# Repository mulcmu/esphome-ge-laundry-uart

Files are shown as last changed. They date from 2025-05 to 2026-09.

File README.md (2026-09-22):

# ESPHome GE Laundry UART

Local Home Assistant control and monitoring for compatible GE appliances through ESPHome and the appliance's GEA serial bus.

> [!WARNING]
> The appliance uses an 8P8C modular connector that looks like Ethernet, but it is **not Ethernet**. Do not connect it to network equipment.

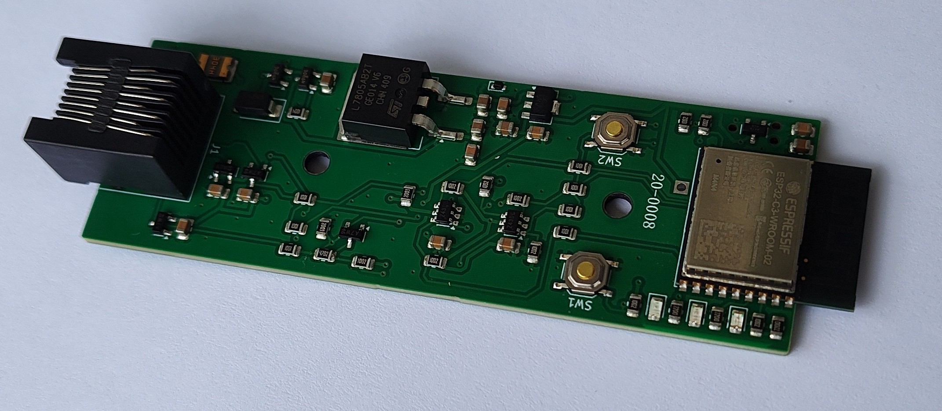
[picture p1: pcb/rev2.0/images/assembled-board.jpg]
Assembled Rev 2-era adapter


The project began as an effort to integrate a GE washer and dryer with Home Assistant. An ESP32 powered by the appliance communication port reports information such as remaining time and cycle completion through ESPHome. Early work involved researching the GEA2 and GEA3 protocols and the U+ Connect module; later, [GE Appliances](https://github.com/geappliances) and [FirstBuild](https://firstbuild.com/inventions/home-assistant-adapter/) published additional hardware and protocol information. The maintained ESPHome implementation now lives in [mguaylam/esphome-gea](https://github.com/mguaylam/esphome-gea), while this repository provides compatible hardware, reference configurations, manufacturing files, and enclosures.

## Getting started

### I already have a board

Follow the [firmware setup guide](firmware/README.md) to choose a GEA2 or GEA3 configuration, flash the board, connect it to Home Assistant, and check the status LEDs. The [Rev 2 enclosure](case/rev2/README.md) includes ready-to-print files.

### I want to order a board

Start with [PCB Rev 2.2](pcb/rev2.2/README.md), then follow the [step-by-step ordering guide](pcb/ORDERING.md). Rev 2.2 corrects the known Rev 2.0 and Rev 2.1 board-file problems.

**Current status:** Rev 2.2 is the recommended manufacturing candidate; physical testing is still pending. A JLCPCB quote checked on September 19, 2026 was **$78.07 before shipping and tax for five fully assembled boards**, or about **$15.61 per board**. Prices and component availability can change.

Older boards and the complete change history are listed in the [PCB revision index](pcb/README.md). Hardware contributors should also read the [contribution guide](CONTRIBUTING.md).

## Related projects

- [GE Appliances organization](https://github.com/geappliances)
- [FirstBuild Home Assistant adapter](https://firstbuild.com/inventions/home-assistant-adapter/)
- [puddly/casserole](https://github.com/puddly/casserole)
- [GEMakers/green-bean](https://github.com/GEMakers/green-bean)
- [doitaljosh/gea-interface-board](https://github.com/doitaljosh/gea-interface-board)
- [doitaljosh/ge-appliances-re](https://github.com/doitaljosh/ge-appliances-re)
- [doitaljosh/geabus-documentation](https://github.com/doitaljosh/geabus-documentation)
- [simbaja/gehome](https://github.com/simbaja/gehome)
- [GE Appliances Home Assistant adapter](https://github.com/geappliances/home-assistant-adapter)
- [GE Appliances Home Assistant examples](https://github.com/geappliances/home-assistant-examples)
- [GE Appliances Home Assistant bridge](https://github.com/geappliances/home-assistant-bridge)

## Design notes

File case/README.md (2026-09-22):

# Enclosures

Enclosure files are grouped by the PCB family they were designed to fit.

[Back to the project overview](../README.md)

| Enclosure | Intended hardware | Status |
| --- | --- | --- |
| [Rev 2 enclosure](rev2/README.md) | Rev 2.x board outline | Existing printable design; Rev 2.2 fit still requires a physical check. |

The editable CAD source, printable files, and documentation images are kept separately. The final check is printing the enclosure and test-fitting an assembled board.

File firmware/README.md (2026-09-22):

# Set up and use a Rev 2.x board

These examples use the maintained [ESPHome GEA component](https://github.com/mguaylam/esphome-gea) to connect the adapter to Home Assistant.

[Back to the project overview](../README.md) · [Recommended PCB Rev 2.2](../pcb/rev2.2/README.md) · [Revision history](../pcb/README.md)

## Choose a configuration

| Configuration | Connection | Typical use |
| --- | --- | --- |
| [`gea2.yaml`](gea2.yaml) | GPIO5 TX and GPIO10 RX, inverted, 19,200 baud | Rev 2.x reference for GEA2 appliances. |
| [`gea3.yaml`](gea3.yaml) | GPIO21 TX and GPIO20 RX, non-inverted, 230,400 baud | Rev 2.x reference for GEA3 appliances. |

The appliance model determines whether it uses GEA2 or GEA3. Start with a configuration already known to work with your appliance rather than trying both while connected.

## Prepare ESPHome

If ESPHome is not installed yet, start with the official [ESPHome installation guide](https://esphome.io/install/) and [getting-started guide](https://esphome.io/install/getting-started/).

1. Copy the matching YAML file into your ESPHome configuration directory.
2. Change the `name` and `upper_name` substitutions near the top of the file.
3. Add these values to the `secrets.yaml` file in the same directory:

```yaml
wifi_ssid: "..."
wifi_password: "..."
esp_home_ota_pw: "..."
```

You can use the ESPHome Device Builder or the command line. The examples are starting points, so appliance-specific entities may need to be added or changed.

## First flash

Rev 2.x boards do not have USB. The first flash needs a **3.3 V logic** USB-to-UART adapter connected to the unpopulated J2 holes or the J3 Tag-Connect pads. Do not connect 5 V to these pins.

| J2 pin | Board signal | Connect to |
| --- | --- | --- |
| 1, square pad | 3.3 V | A regulated 3.3 V source capable of powering the ESP32 |
| 2 | Ground | Adapter ground |
| 3 | Boot | Ground only while entering the bootloader |
| 4 | Board TX | Adapter RX |
| 5 | Board RX | Adapter TX |
| 6 | Enable | Optional reset control |

Use only one power source at a time. Some USB-to-UART adapters cannot provide enough 3.3 V current for an ESP32 Wi-Fi board; use a separate regulated 3.3 V supply when needed and connect its ground to the adapter ground.

1. Connect J2 Boot to Ground.
2. Apply 3.3 V power, or power-cycle the board if it was already on. This starts the serial bootloader.
3. In ESPHome Device Builder, choose **Install** and select the serial adapter. With the command line, run:

   ```console
   esphome run your-config.yaml --device /dev/cu.your-usb-serial-device
   ```

4. When the upload finishes, disconnect Boot from Ground and power-cycle the board.

Later updates can be installed over Wi-Fi from ESPHome Device Builder. From the command line, run the same `esphome run` command and choose the network device when prompted.

## Connect to the appliance

1. Disconnect the programming adapter and install the board in its enclosure.
2. With the appliance off, connect the adapter to its service port. This connector is not Ethernet.
3. Power the appliance and wait for the board to join Wi-Fi.
4. Add the discovered ESPHome device in Home Assistant.

With the supplied configurations, the green LED shows Wi-Fi connection and the yellow LED shows GEA bus activity. The red LED is available to ESPHome but is not assigned a status by these examples.

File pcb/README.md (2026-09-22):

# PCB revisions

This directory keeps every board revision in a separate package so source files, manufacturing files, and review files do not get mixed between revisions.

[Back to the project overview](../README.md) · [PCB ordering guide](ORDERING.md)

> [!IMPORTANT]
> For a new build, start with [Rev 2.2](rev2.2/README.md). Older revisions are retained for repair information and project history.

## What the folders mean

- `design/` contains the editable KiCad project. A `.pretty` directory under `footprints/` is a KiCad footprint library: it defines the exact copper pads, drill holes, silkscreen, and component outline used on the board. A project `fp-lib-table` maps the library name used by the board to that local directory so footprints resolve from a clean clone. A `models/` directory, when present, contains optional 3D component shapes.
- `manufacturing/` contains files sent to a PCB assembler. Gerbers describe copper, holes, solder mask, and silkscreen; the BOM lists components; the CPL lists component positions and rotations.
- `validation/` contains files used to review the design, such as schematic PDFs, board views, drill maps, and ERC/DRC reports.
- `images/` contains photographs and explanatory renders used by documentation. Images are not manufacturing inputs.

## Revision index

| Revision | Status | Available material |
| --- | --- | --- |
| [Rev 2.2](rev2.2/README.md) | Manufacturing candidate | Corrected KiCad source, matched factory package, and validation exports. |
| [Rev 2.1](rev2.1/README.md) | Built; superseded | KiCad 9 source, JLCPCB package, drill maps, and repair image. |
| [Rev 2.0](rev2.0/README.md) | Built; superseded | PCBA archive, schematic, board model, renders, and photographs. |
| [Rev 1.0](rev1.0/README.md) | Historical | Gerber archive only. |

> [!IMPORTANT]
> Rev 2.0 and Rev 2.1 have swapped RX/TX silkscreen labels. Their U1 reset supervisor can also cause ESP32 boot loops. Do not treat either manufacturing package as a corrected design.

Rev 2.2 addresses those known board-file problems but is not proven until assembled boards pass electrical, appliance, and enclosure testing. Use only the three matched files in its `manufacturing/` directory when ordering.

Not every revision has the same files. The table lists what is actually available; missing source files, exports, and images were not recreated.

## Historical revisions

- Rev 0.1 had unconnected grounds discovered after ordering.
- Rev 0.2 corrected the grounds but needed a diode orientation bodge and resistor changes.
- Rev 0.3 added test points, an LED, a push button, and protection diodes; three boards were tested.
- Rev 1.0 added configurable resistors for inverted GEA2 serial signaling.
- Rev 2.0 introduced an assembly-oriented ESP32-C3 design.
- Rev 2.1 updated that design and migrated its source to KiCad 9.

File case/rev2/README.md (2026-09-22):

# Rev 2 enclosure

This enclosure was designed around the Rev 2.x PCB outline. The editable Fusion 360 archive, neutral CAD export, printable STL files, and documentation images are kept separately.

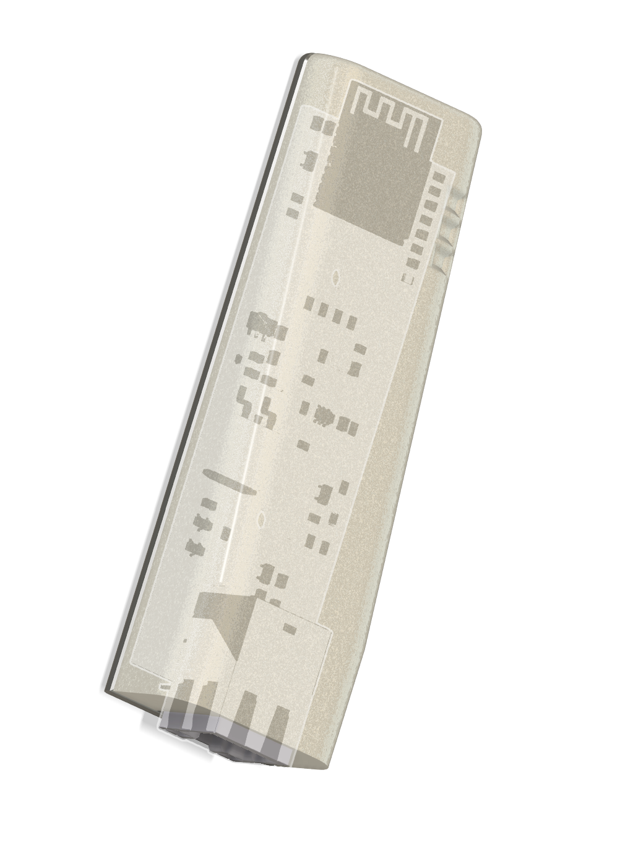
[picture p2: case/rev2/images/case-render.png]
Rev 2 enclosure render


*Exterior enclosure render.*

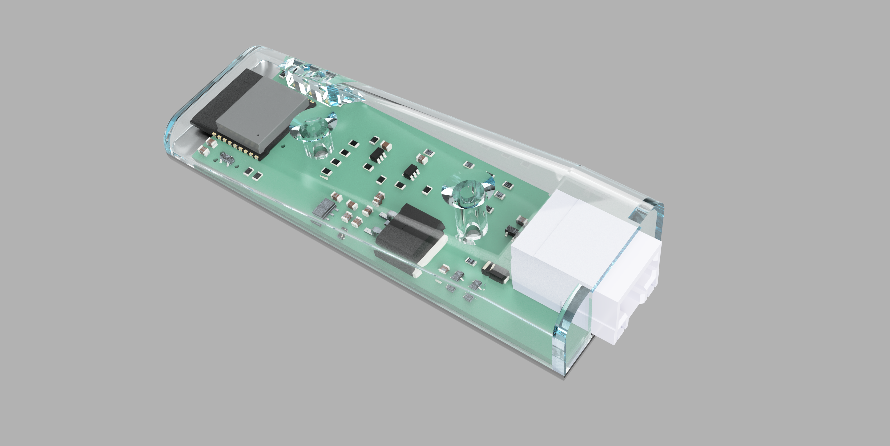
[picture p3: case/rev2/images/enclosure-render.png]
Rev 2 enclosure with board


*Exploded enclosure view showing the board position.*

## Files

- [Editable Fusion 360 archive](v2-case.f3z)
- [STEP export](exports/v2-case.step)
- [Base STL](exports/v2-case-base.stl)
- [Lid STL](exports/v2-case-lid.stl)
- [Case render](images/case-render.png)
- [Enclosed-board render](images/enclosure-render.png)
- [Example support arrangement](images/print-supports.png)

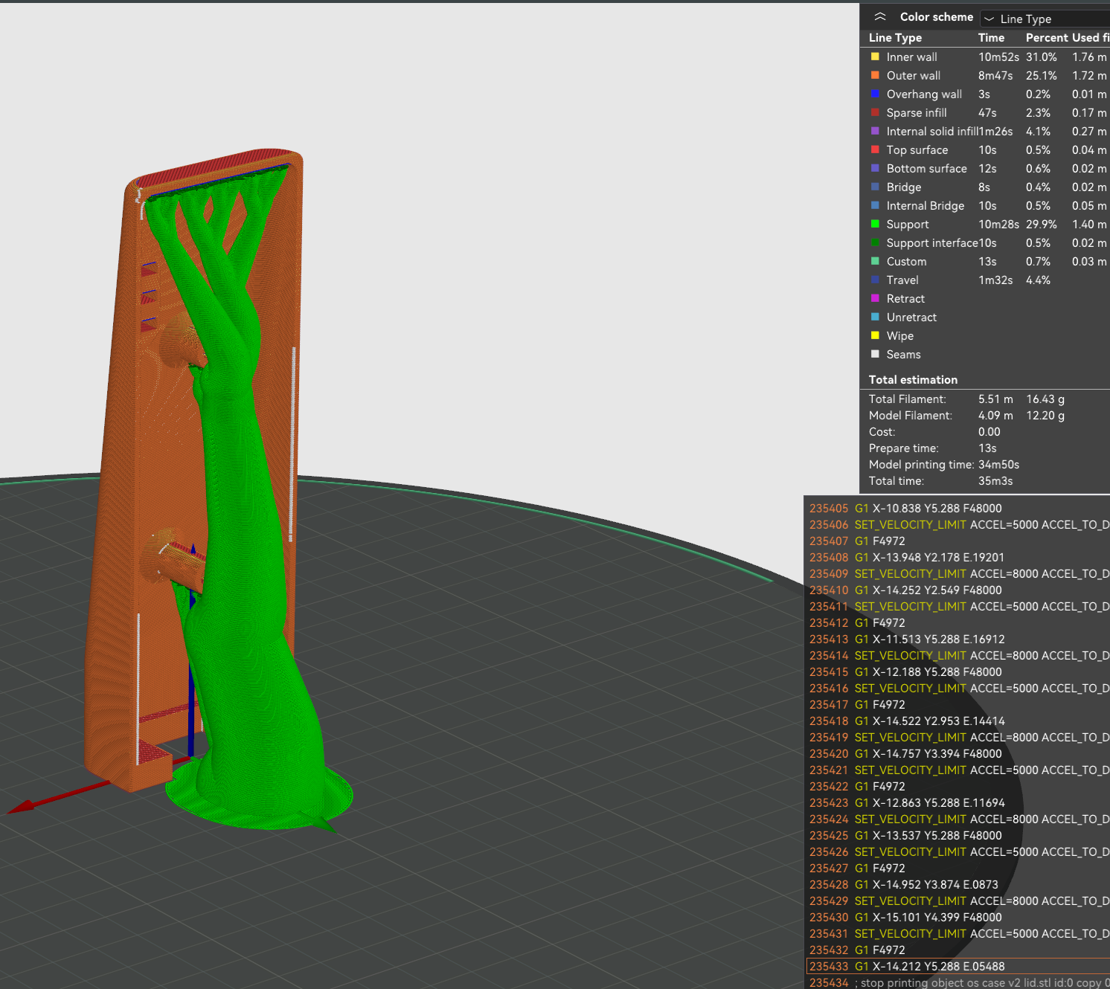
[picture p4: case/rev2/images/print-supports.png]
Example print support arrangement


*Example slicer support arrangement.*

The support image is an example, not a required slicer profile. Confirm orientation, support placement, connector access, button access, antenna clearance, and populated-board fit before relying on a print.

[Back to the enclosure index](../README.md) · [PCB revisions](../../pcb/README.md)

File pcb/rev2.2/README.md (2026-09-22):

# PCB Rev 2.2 manufacturing candidate

This directory contains the matched files needed to quote a small revision 2.2 prototype batch. Revision 2.2 is not a proven hardware release until physical boards pass bring-up testing.

Start with the [KiCad project](design/OnionStraws.kicad_pro). Use the shared [PCB ordering guide](../ORDERING.md) with the three matched Rev 2.2 manufacturing files; do not substitute files from an older revision.

## What changed

- `U1` is an optional voltage-monitor chip intended to reset the ESP32 when its supply is too low. It caused repeated boot loops on existing Rev 2 boards, so Rev 2.2 leaves it uninstalled. Its small footprint remains on the board for rework, but the factory BOM and placement data exclude it. R3 still keeps the ESP32 enabled. Neither board button is wired as a reset button; reset requires a power cycle or an external reset connection.
- The rear silkscreen identifies the board as revision 2.2.
- The appliance-facing connector labels now use the adapter/ESP perspective:
  - pin 5, `Full TX`: adapter/ESP TX to appliance RX;
  - pin 4, `Full RX`: appliance TX to adapter/ESP RX.
- `Q1` is one of two identical power-control transistors. Its supplier catalog field was blank, while `Q2` already identified the correct part. Rev 2.2 gives both the same LCSC catalog number so JLCPCB can source the part automatically. This is purchasing metadata only and does not change the circuit.
- `J1` retains the original low-cost EVERCOM `5301-8P8C` (`C3097717`). Its eight signal holes now use the manufacturer's recommended 0.90 mm diameter; the connector position and two 3.20 mm locating holes are unchanged. Confirm the connector orientation and drill pattern in the vendor preview and prototype batch before production use.
- `JP1` and `JP2` are existing three-pad solder selectors on the bottom of the board. `JP1` selects the FirstBuild-compatible signal mapping. `JP2` selects the normal or alternate appliance power input. Both default to pads 1-2 because that copper bridge is part of the manufactured board; changing one requires cutting that bridge and soldering pads 2-3.

Rev 2.2 does not add a new user-operated jumper, programming connector, or automatic pin-1/pin-3 power-selection circuit. The service pads and solder selectors described below already existed in Rev 2.1 and remain unpopulated. Do not combine the [Rev 2.1 package](../rev2.1/README.md) with Rev 2.2 files.

## Debug and programming access

Rev 2.2 preserves two service interfaces, both excluded from factory assembly:

- `J2` is a row of six 2.54 mm through-holes carrying, from square pin 1 to pin 6, 3.3 V, ground, boot, board transmit, board receive, and enable. Revision 2.2 leaves these holes unpopulated. A header may be soldered into them later, or a custom pogo fixture may contact them.
- `J3` carries the same six signals on a flat, bottom-side Tag-Connect `TC2030-IDC-NL` pattern. It has copper contacts and three alignment holes but no connector component, so it adds no BOM or assembly cost. A compatible cable or reusable pogo clip can make a no-solder connection.

Neither interface is USB. Connecting a Mac requires a 3.3 V USB-to-UART adapter plus the matching cable or fixture; do not connect 5 V logic to these signals. The current Rev 2 enclosure covers both service areas and is unchanged in this revision.

## Manufacturing files

- [`GERBER-OnionStraws-rev2.2.zip`](manufacturing/GERBER-OnionStraws-rev2.2.zip): two-layer Gerbers, plated and non-plated drill files, and the Gerber job file.
- [`BOM-OnionStraws-rev2.2.csv`](manufacturing/BOM-OnionStraws-rev2.2.csv): JLCPCB-ready assembly BOM with DNP parts excluded.
- [`CPL-OnionStraws-rev2.2.csv`](manufacturing/CPL-OnionStraws-rev2.2.csv): JLCPCB-ready top-side placement data for the installed parts, including through-hole J1. U1 and the unpopulated J2 header are excluded.

## Validation exports

- [Schematic PDF](validation/schematic.pdf)
- [Top-side 2D board view](validation/board-top.png)
- [Bottom-side 2D board view](validation/board-bottom.png)

These exports are generated from the Rev 2.2 KiCad sources without editor chrome, grid, or net labels. The J1 footprint intentionally has no 3D model until an exact EVERCOM model is verified.

The red X marks in the schematic are KiCad **Do Not Populate** indicators. They identify footprints intentionally left unassembled, including U1 and the optional service interfaces; they are not broken wires or ERC errors. The embedded board rendering is an orientation aid and may omit components for which no verified 3D model is available.

## Parts to recheck when ordering

These are the intended parts. Inventory changes, so confirm them on the order screen.

| Designator | Value/package | Part | LCSC | Notes |
| --- | --- | --- | --- | --- |
| R22 | 4K7 / 0805 | UNI-ROYAL `0805W8F4701T5E` | [C17673](https://lcsc.com/product-detail/Chip-Resistor-Surface-Mount_Uniroyal-Elec-0805W8F4701T5E_C17673.html) | 4.7 kΩ, ±1%, 125 mW, 150 V, −55 to +155 °C, 0805; check current stock |
| R18, R21 | 220k / 0805 | RALEC `RTT052203FTP` | [C104108](https://www.lcsc.com/product-detail/C104108.html) | 220 kΩ, ±1%, 125 mW, 150 V, −55 to +155 °C, 0805; check current stock |
| U4, U5 | 74LVC2G07 / SOT-23-6 | DIODES `74LVC2G07W6-7` | [C151607](https://www.lcsc.com/product-detail/C151607.html) | Correct package and pinout; check current stock |
| U6 | AP2205-3.3 / SOT-89-3 | TECH PUBLIC `TPAP2205-33Y` | [C19268131](https://www.lcsc.com/product-detail/C19268131.html) | 3.3 V, 200 mA, 30 V LDO, SOT-89-3; LCSC lists it as a substitute for the original `C5205181`; confirm current stock |

## Current status

Rev 2.2 is the recommended manufacturing candidate, but physical bring-up testing is still pending. A JLCPCB quote checked on September 19, 2026 was **$78.07 before shipping and tax for five fully assembled boards**, or about **$15.61 per board**. See the [ordering guide](../ORDERING.md) for the short ordering process.

## Rev 2.2 order and test checks

- Upload only the Rev 2.2 Gerber ZIP, BOM, and CPL together. Confirm the preview shows a 2-layer, 1.6 mm, approximately 88.6 mm by 30.0 mm board.
- Confirm all 59 assembled designators are recognized and U1 and J2 are absent. Recheck the listed catalog parts and U4/U5/U6 availability in the live quote.
- Confirm J1 is EVERCOM `5301-8P8C` (`C3097717`), its socket opens toward the short board edge, and its eight pins and two locating posts align with the drill preview. Stop if the assembler will not install it unless hand soldering is acceptable.
- Confirm whether the target appliance supplies power on connector pin 1 or pin 3. Rev 2.2 retains the existing pin-1 default through `JP2`; selecting pin 3 requires cutting and soldering the bottom-side selector.
- During first bring-up, power the adapter from one source at a time, verify the 5 V and 3.3 V rails, and confirm repeated stable boots without U1.

KiCad 9.0.9 reports the same ERC and DRC issues as Rev 2.1, with no new categories. The Gerber ZIP also passes its integrity check. Physical testing is still outstanding.

[Back to the PCB revision index](../README.md) · [Ordering guide](../ORDERING.md) · [Rev 2 enclosure](../../case/rev2/README.md) · [Firmware examples](../../firmware/README.md)

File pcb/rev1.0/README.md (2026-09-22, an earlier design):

# PCB Rev 1.0

Rev 1.0 added three resistor positions so inverted GEA2 serial signaling could be configured with pull-up or pull-down resistors.

This is a historical release. The active tree retains only the original [Gerber archive](manufacturing/GERBER-OnionStraws-rev1.0.zip); editable design files remain available through Git history.

[Back to the PCB revision index](../README.md)

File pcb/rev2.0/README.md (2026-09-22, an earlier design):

# PCB Rev 2.0

Rev 2.0 reworked the board for automated assembly and adopted an ESP32-C3 module and pinout compatible with the project direction at the time.

> [!WARNING]
> The RX and TX silkscreen labels are swapped. U1 can cause ESP32 boot loops. This revision is retained for history and is not the recommended starting point for a new order.

## Files

- [Historical PCBA archive](manufacturing/PCBA-OnionStraws-rev2.0.zip)
- [Schematic PDF](validation/schematic.pdf)
- [Board render](validation/board-render.png)
- [Board STEP model](validation/board.step)
- [Historical board photograph](images/assembled-board.jpg)

The photograph was stored as `v2.jpg` in the repository root. Its exact Rev 2.x subrevision was not recorded.

No editable KiCad source was included with the retained Rev 2.0 artifacts, and none was reconstructed for this archive.

[Back to the PCB revision index](../README.md) · [Rev 2 enclosure](../../case/rev2/README.md) · [Firmware examples](../../firmware/README.md)

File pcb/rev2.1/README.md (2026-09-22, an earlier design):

# PCB Rev 2.1

Rev 2.1 is the latest built Rev 2.x design before the corrective Rev 2.2 work. Its KiCad project was migrated to KiCad 9.

> [!WARNING]
> The RX and TX silkscreen labels are swapped. U1 can cause ESP32 boot loops. The manufacturing files are preserved for history and should not be mistaken for a corrected release.

## Files

- [Open the KiCad project](design/OnionStraws.kicad_pro)
- [Schematic source](design/OnionStraws.kicad_sch)
- [PCB source](design/OnionStraws.kicad_pcb)
- [Gerber archive](manufacturing/GERBER-OnionStraws-rev2.1.zip)
- [Bill of materials](manufacturing/BOM-OnionStraws-rev2.1.csv)
- [Component placement list](manufacturing/CPL-OnionStraws-rev2.1.csv)
- [Plated-hole drill map](validation/pth-drill-map.pdf)
- [Non-plated-hole drill map](validation/npth-drill-map.pdf)
- [U1 trace-removal illustration](images/u1-trace-fix.png)

The PCB silkscreen identifies this source as Revision 2.1, while the inherited schematic title block still says 2.0. The historical files are unchanged, and this README calls out the mismatch.

No schematic PDF or board-view image was included with the retained Rev 2.1 artifacts, and those exports were not reconstructed.

[Back to the PCB revision index](../README.md) · [Rev 2 enclosure](../../case/rev2/README.md) · [Firmware examples](../../firmware/README.md)

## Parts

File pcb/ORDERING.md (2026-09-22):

# Order a Rev 2.2 board

You do not need KiCad to order the board. This guide uses JLCPCB, but another PCB assembly company can use the same files.

[Back to the project overview](../README.md) · [PCB revision index](README.md)

> [!NOTE]
> Rev 2.2 has not yet been tested as an assembled board. Order the minimum quantity first. If you want to wait for tested hardware, check the [Rev 2.2 status](rev2.2/README.md) before ordering.

## Download these three files

- [Gerber ZIP](rev2.2/manufacturing/GERBER-OnionStraws-rev2.2.zip): the board itself
- [BOM](rev2.2/manufacturing/BOM-OnionStraws-rev2.2.csv): the parts list
- [CPL](rev2.2/manufacturing/CPL-OnionStraws-rev2.2.csv): where the parts go

Keep these three Rev 2.2 files together. Do not use a BOM or CPL from an older revision.

## Place the order

1. Open the JLCPCB PCB quote page and upload the Gerber ZIP.
2. The site should detect a 2-layer board about 88.6 mm by 30.0 mm. Use the standard 1.6 mm board thickness.
3. Choose five PCBs and enable PCB assembly for all five boards.
4. Select economic, top-side assembly.
5. Upload the Rev 2.2 BOM and CPL when prompted.
6. Review the board and component-placement previews. Resolve any missing, unselected, or obviously misplaced parts before continuing.

## Current price estimate

A JLCPCB quote checked on September 19, 2026 was **$78.07 before shipping and tax for five fully assembled boards**, or about **$15.61 per board**. Treat this as a dated estimate because component stock and pricing change.

## Before paying

Before continuing, check that:

- The board is about 88.6 mm by 30.0 mm and has two layers.
- Assembly is enabled for all five boards on the top side.
- The component-placement preview looks aligned with the board.
- The parts list has no unresolved or unselected items.

The [Rev 2.2 page](rev2.2/README.md) has the full part list and board images if you need to compare them with the order screen.

## When the boards arrive

1. Check for bent connectors, loose parts, or visible solder bridges.
2. Follow the [firmware setup guide](../firmware/README.md) to flash the board.
3. Do not connect it to an appliance until the 3.3 V and 5 V power rails have been checked. Rev 2.2 is still awaiting its first assembled-board test.

If you do not have the tools to check the power rails, wait until the first Rev 2.2 batch has been tested and the results are posted.

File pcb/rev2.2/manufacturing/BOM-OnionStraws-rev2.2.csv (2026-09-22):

Comment | Designator | Footprint | LCSC Part # | Quantity
100n | C1,C3,C4,C5,C6,C7,C10,C12,C14 | C_0805_2012Metric | C28233 | 9
1u | C2,C8 | C_0805_2012Metric | C28323 | 2
10u | C9,C11,C13 | C_0805_2012Metric | C15850 | 3
GRN | D4 | LED_0805_2012Metric | C2297 | 1
RED | D5 | LED_0805_2012Metric | C84256 | 1
YLW | D6 | LED_0805_2012Metric | C2296 | 1
D_TVS | D7 | D_SMA | C309871 | 1
5.2V | D8 | D_SOD-123 | C78479 | 1
BAV99 | D1,D2,D3,D9 | SOT-23 | C2500 | 4
Polyfuse | F1,F2 | Fuse_1812_4532Metric | C12604 | 2
8P8C | J1 | RJ45_EVERCOM_5301-8P8C_Horizontal | C3097717 | 1
Si2309CDS | Q1,Q2 | SOT-23 | C10493 | 2
1M | R9 | R_0805_2012Metric | C17514 | 1
4K7 | R22 | R_0805_2012Metric | C17673 | 1
10K | R1,R2,R3,R5,R14,R15,R16,R17,R19,R20 | R_0805_2012Metric | C17414 | 10
1K | R10,R11,R12,R13,R23,R24,R25 | R_0805_2012Metric | C17513 | 7
220k | R18,R21 | R_0805_2012Metric | C104108 | 2
220 | R4,R6,R7 | R_0805_2012Metric | C17557 | 3
SW_Push | SW1,SW2 | SW_Push_1P1T_XKB_TS-1187A | C318884 | 2
ESP32-C3-WROOM-02 | U2 | ESP32-C3-WROOM-02 | C2934560 | 1
L7805 | U3 | TO-263-2 | C86206 | 1
74LVC2G07 | U4 | SOT-23-6 | C151607 | 1
74LVC2G07_3v3 | U5 | SOT-23-6 | C151607 | 1
AP2205-3.3 | U6 | SOT-89-3 | C19268131 | 1

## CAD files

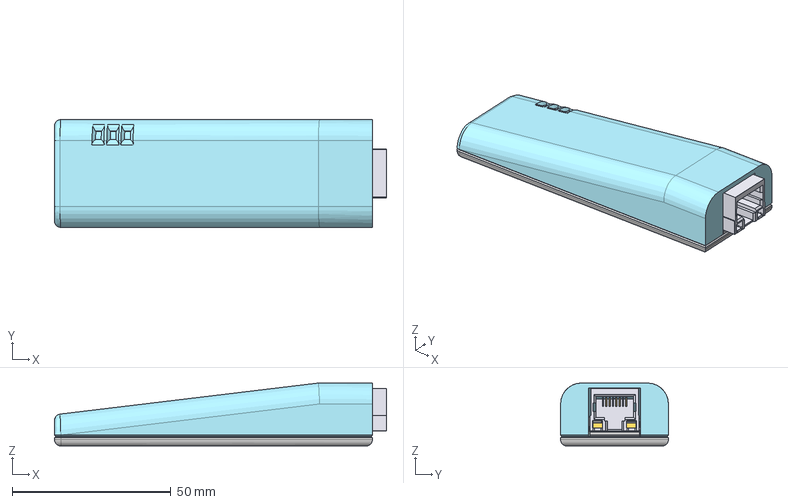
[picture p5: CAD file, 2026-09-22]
case/rev2/exports/v2-case.step
104.6 x 34.0 x 19.9 mm
C_0805_2012Metric_1 x 14
R_0805_2012Metric_1 x 24
SOT_23 x 7
LED_0805_2012Metric_1 x 3
SOT_23_6 x 2
ESP32-C3-WROOM-02_1
CQ assembly
D_SOD_523
CQ assembly_1
D_SMA_1
OnionStraws_PCB
Insulator
Insulator_2
LED_green_yellow
Insulator_3

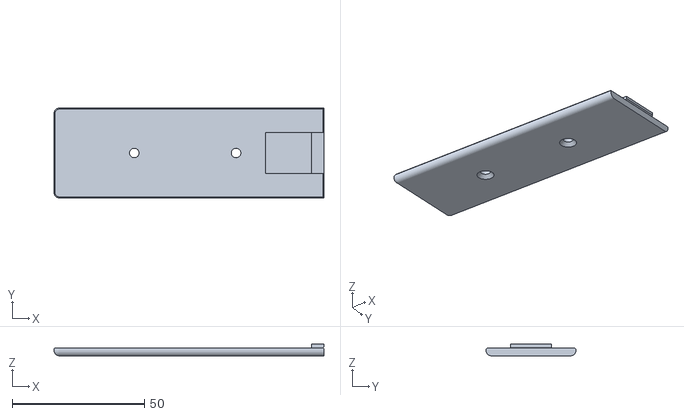
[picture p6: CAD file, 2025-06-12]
case/rev2/exports/v2-case-base.stl
102.2 x 34.0 x 4.40

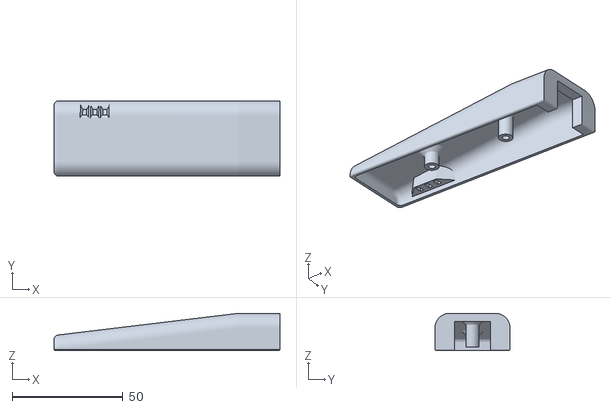
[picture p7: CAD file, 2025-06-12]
case/rev2/exports/v2-case-lid.stl
102.2 x 34.0 x 16.9

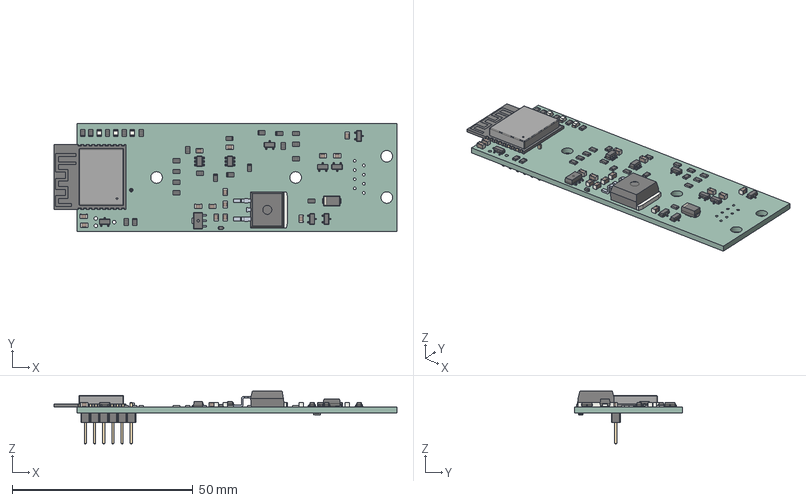
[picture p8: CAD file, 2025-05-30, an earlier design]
pcb/rev2.0/validation/board.step
95.0 x 30.0 x 14.7 mm
C_0805_2012Metric x 14
R_0805_2012Metric x 25
SOT_23 x 7
LED_0805_2012Metric x 3
SOT_23_6 x 2
ESP32-C3-WROOM-02
CQ assembly x 2
D_SOD_523
D_SMA
PinHeader_1x06_P254mm_Vertical
OnionStraws_PCB

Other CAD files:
case/rev2/v2-case.f3z

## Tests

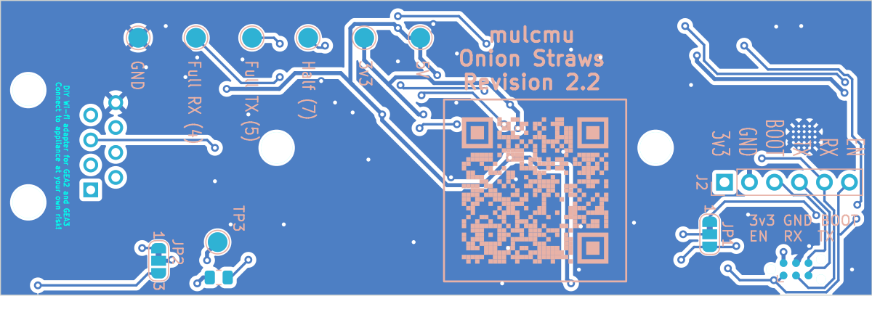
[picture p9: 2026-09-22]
pcb/rev2.2/validation/board-bottom.png

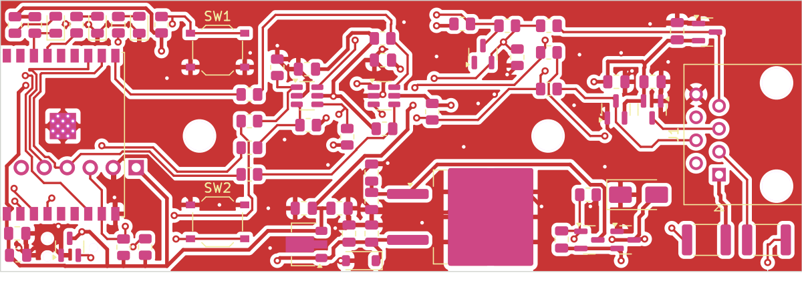
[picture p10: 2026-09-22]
pcb/rev2.2/validation/board-top.png

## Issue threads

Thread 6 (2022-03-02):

TX data format

JohnnyPicnic, 2022-03-02:
Hi, have you been able to send message to you GE devices?
I'm using a USB FTDI Serial adapter which is working great but I haven't figured out how to do hardware control for TX.
While I figure that out I'm trying to figure out the proper format for sending messages.

I believe bf is the knobs on my oven
Use “Upper Oven Remote Enable” ERD  (0x510A) – e.g. write ERD and enable
	•	Sample data [Source Address, 0xF1 (ERD write), 0x01 (1 ERD), 0x51, 0x0A (ERD), 0x01 (size), 0x01 (enable)]
Does that mean the hex code should be E2 bf F1 01 51 0A 01 01 CRC CRC E3 ?

mulcmu, 2022-03-03:
Yes, I have been able to send and receive to washer and dryer.  Washer had separate RX & TX lines, full duplex.  There wasn't any traffic on these lines until serial adapter or ESP32 started to request data.  Dryer has RX & TX on same line, half duplex.  The dryer main board seemed to be sending packets to internal wifi module that wasn't installed on my unit.  So I was able to see some traffic without initiating a request.

Your sample [packet ](https://github.com/doitaljosh/ge-appliances-re/blob/master/geabus-packet-structure.png)is missing the size/length and source address.

E2 Start Byte
BF Destination
0D Size (13 bytes in packet)
BB Source (Address the serial adapter is going to assume)
F1 ERD write
01 Single Erd
51 Erd High byte
0A Erd Low Byte
01 Size of data
01 Data to set
CRC
CRC
E3

0XBF looks like it is the universal wifi module from this [link](https://github.com/doitaljosh/ge-appliances-re/blob/master/reverse-engineering.txt)

Based on my testing the CRC needed to be correct otherwise the appliance would not respond.

Here was packet that should request all of the devices in appliance respond with their firmware revision.  This can be used to figure out which boards in oven are at what address.

`std::vector<uint8_t> fw_broadcast= {0XE2, 0XFF, 0X08, 0XBB, 0X01, 0X9A, 0X85, 0xE3};    //FW broadcast message`

What baud rate was the oven using and did you need to setup the FTDI to invert the serial polarity?

JohnnyPicnic, 2022-03-04:
Yup the baud rate was standard 19200 and yes I had to invert the signal using FT Prog. I don't know why I'm having such a hard time figuring out half duplex with the FTDI. For your setup it's all done through diodes?
I'm trying to do everything with Node Red. I've a got CRC 16 function node working and now just need to figure out how to transmit.

mulcmu, 2022-03-05:
The ESP32 hardware has an option for inverting the serial polarity, this is getting implemented in my setup with the ESPHome configuration.

The U1 and U2 74LVC2G07 is a non inverting buffer used to shift voltage level from 5V to 3.3V for ESP.  The resistor/diode (R5/D4) was added based on this [article](https://circuitcellar.com/resources/ee-tips/one-wire-rs-232-half-duplex-ee-tip-135/).  The inverted TTL idle state is 0V.  The diode allows the appliance to put 5V on the bus line without the U2A buffer fighting to pull it back down to 0V.

JohnnyPicnic, 2022-03-05:
Thanks for the link to the article. If I already have the signal inverted and don't need voltage shifting do you think the R5/D4 combo would be all I need? I have no problem with just RX connected but once I add TX the data is echoed and probably corrupted. I didn't' notice it but is there any timing involved in your ESP32 code?
I may move to an ESP32 but would still like to parse all the data through Node Red.

mulcmu, 2022-03-05:
Nothing too critical timing wise.  The send was done after reading and processing the RX input buffer.  Before sending the packet I just checked to see if any new bytes showed up on RX port and would abort if so.  The dryer would repeat the response 3 times unless the `e1` acknowledge byte was sent promptly.

If your oven has built in wifi, it might be harder to find an open window to TX if there is a lot of other traffic.  I don't recall seeing where any timing was discussed in the other related projects.

JohnnyPicnic, 2022-03-09:
I made the circuit you used for your board and I think i'm getting a response the command you suggested.
TX:
0XE2, 0XFF, 0X08, 0XBB, 0X01, 0X9A, 0X85, 0xE3
RX:
e2bb0cbf 01 00 01 05 6c 25 ab e3
e2bb0cbc 01 00 01 00 14 eb 21 e3
e2bb0cbf 01 00 01 05 6c 25 ab e3
e2bb0cbf 01 00 01 05 6c 25 ab e3
e2bb0cbc 01 00 01 00 14 eb 21 e3
e2bb0cbc 01 00 01 00 14 eb 21 e3
e2bb0cbc 01 00 01 00 14 eb 21 e3

mulcmu, 2022-03-25:
Have you made any more progress getting FTDI to work with oven?

JohnnyPicnic, 2022-03-25:
Not really. No other command seemed to give me a response.
I ordered a FT260 HID-class USB to I2C/UART module in hopes of emulating the Green Bean.

mulcmu, 2022-03-25:
I have a few extra of the Rev 0.3 pcb built if you want one of those to try.  You'll just need to supply the ESP32.

JohnnyPicnic, 2022-03-26:
Thats a really generous offer. How much? Shipping would be to Edmonton, Alberta, Canada.

mulcmu, 2022-03-27:
No charge for PCB just cover the shipping.  Email is mulcmu at yahoo.

mguaylam, 2024-10-07:
Have you guys seen this? https://github.com/geappliances/tiny-gea3-api

mulcmu, 2024-10-07:
Thanks.  They also posted the erd list in another repository: https://github.com/geappliances/public-appliance-api-documentation

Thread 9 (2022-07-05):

Support USB powering (warn/omit buck and supervisor)

mightymos, 2022-07-05:
Success!

My onion board was connected by Ethernet cable only to GTW460ASJ6WW (washer).
However by monitoring USB serial output ESP32 would continuously reset when attempting wifi setup.
This implied the washer +9V supply was not handling a current increase during wifi setup.

I decided to try powering from USB wall charger (had in drawer 5V 700mA capacity).
I needed to remove buck converter since it appeared to be back feeding.
I also had to remove APX803L since it was holding ESP32 in reset.

Finally connected both Ethernet cable and USB charger to ESP32 USB port and powered up correctly!
Added the esphome integration in Home Assistant and shows sensors as Unknown state, but they are timestamped as updating.

I think the supervisor is APX803L40-50SA for 5V threshold.
I think USB power results in 4.85 V so supervisory is holding reset.
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

If desired to use USB power could 1) add a warning not to populate or 2) use lower threshold supervisor?

[esp32_washer_powered_reset.txt](https://github.com/mulcmu/esphome-ge-laundry-uart/files/9043614/esp32_washer_powered_reset.txt)
[GTW460ASJ6WW_Washer_WiringDiagram.pdf](https://github.com/mulcmu/esphome-ge-laundry-uart/files/9043615/GTW460ASJ6WW_Washer_WiringDiagram.pdf)

mulcmu, 2022-07-13:
The DC/DC converter comes with an adjustment pot and also solder set points for a fixed voltage.  I removed the adjustment pot and (in lieu of cutting the pot trace as recommended by supplier) and soldered the 5V jumper closed.  This gave right around 5V under load with a 15V input on the bench.  I was concerned about inadvertent adjustment of the pot during use.  I wonder if the 9V supply from the washer would work if converter was adjusted in circuit to give 5V with the 9V input.

I ran into a problem with the 5V supervisor on another project and switched to 3.3V for that design.  It was an ESP8266 bare module vs ESP32 dev board.  I think not populating might be better solution as the dev board might already have an RC delay on the EN pin.

mightymos, 2022-07-13:
For the pot if that's how it comes, would probably be better to set and then hot glue or nail polish to fix shaft non-destructively.
Maybe some ESP32 have brown out detector but it's not clear to me which from quick searches.
I think it used to be pretty common that almost all microcontrollers basically had to have power up reset built in.

With the external supervisor they sell thresholds fixed at increments of tenth of a volt.
If still wanted, could probably install one with a fixed threshold a little less than 5V to give some wiggle room (e.g., 4.8 V).
Specific threshold chosen depends on what the ESP32 requires as minimum or typical range near 5V to be considered stable.

I ended up installing SIP connector to act as socket for buck converter.
I destroyed the buck removing it. :(
I can try some experiments, what's the part number on that buck board?

mulcmu, 2022-07-19:
Here was the [link](https://www.google.com/url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) for buck converter B08R6337QY

mightymos, 2022-08-01:
I did buy a slightly different buck module (B0758ZTS61 - just to receive fewer quantity).
I set it about 5V on breadboard by potentiometer and confirmed it maintained voltage in circuit with no further adjustment.
I think there's an OR-ing diode in there too (in case USB power is also connected) but apparently not much voltage drop.

The board has been powered up for several days with no drops from wifi or Home Assistant.
No voltage supervisor has been reinstalled so can not speak to that.

Unfortunately have no apparent communication to washer but confirms working hardware/software.

Closed 2022-08-01.

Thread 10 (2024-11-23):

Support for water heaters

ablyler, 2024-11-23:
I am the maintainer for the [Home Assistant Bradford White Connect](https://github.com/ablyler/home-assistant-bradford-white-connect). The connect device appears to be a ESP32 board that is talking the GEA2 protocol to the water heater via a RJ45 connection.

I am interested in helping add support for water heaters with your project or creating a sibling project. Any help you could provide me on how to get started would be great! I am new to all this low level stuff. How can I use your PCB board design to build a board that I could start iterating on?

I did find this [documentation](https://github.com/doitaljosh/geabus-documentation/blob/master/hewh-interface.docx) that appears to be a good start for how to send commands to the water heater.

mguaylam, 2024-11-23:
You can buy the board from FirstBuild or look here : https://github.com/geappliances/home-assistant-adapter/blob/main/doc/schematic-v1.0.pdf

ablyler, 2024-11-23:
> You can buy the board from FirstBuild or look [here](https://github.com/geappliances/home-assistant-adapter/blob/main/doc/schematic-v1.0.pdf).

I tried to find the board on FirstBuild, but couldn't find it. Do you have a link?

mulcmu, 2024-11-23:
I had used a lot of the information from the doitaljosh repositories when I was developing this project.

The other FirstBuild/GeMakers repository has official details on the water heater [erds](https://github.com/geappliances/public-appliance-api-documentation/blob/36e7e1dbee7e1ad33003941ec5ac44ccb20b119b/appliance_api.json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).  They also have a home assistant repository so it looks like some nice non-cloud stuff is being developed.  A big change from where they were about a year [ago](https://hackaday.com/2024/01/19/haier-threatens-legal-action-against-home-assistant-plugin-developer/).

mguaylam, 2024-11-23:
I do have the board working if you have any questions.

ablyler, 2024-11-24:
> I do have the board working if you have any questions.

Did you get the board from FirstBuild or build it yourself? It looks like the board supports gea2, but I only see gea3 referenced in their code.

mguaylam, 2024-11-24:
Yes I got it from FirstBuild. I believe the board support GEA2 & 3 but they only implemented GEA3 for now. You could ask on this [repo](https://github.com/geappliances/home-assistant-adapter) perhaps? They wrote the [tiny gea3 api](https://github.com/geappliances/tiny-gea3-api) so I guess someone would need to do the same for GEA2.

ablyler, 2024-11-24:
Thanks! I actually posted an [issue](https://github.com/geappliances/home-assistant-adapter/issues/5) a bit ago on that repo. 😀 We can close this issue, as I think I'll pursue the FirstBuild route.

Closed 2024-11-24.

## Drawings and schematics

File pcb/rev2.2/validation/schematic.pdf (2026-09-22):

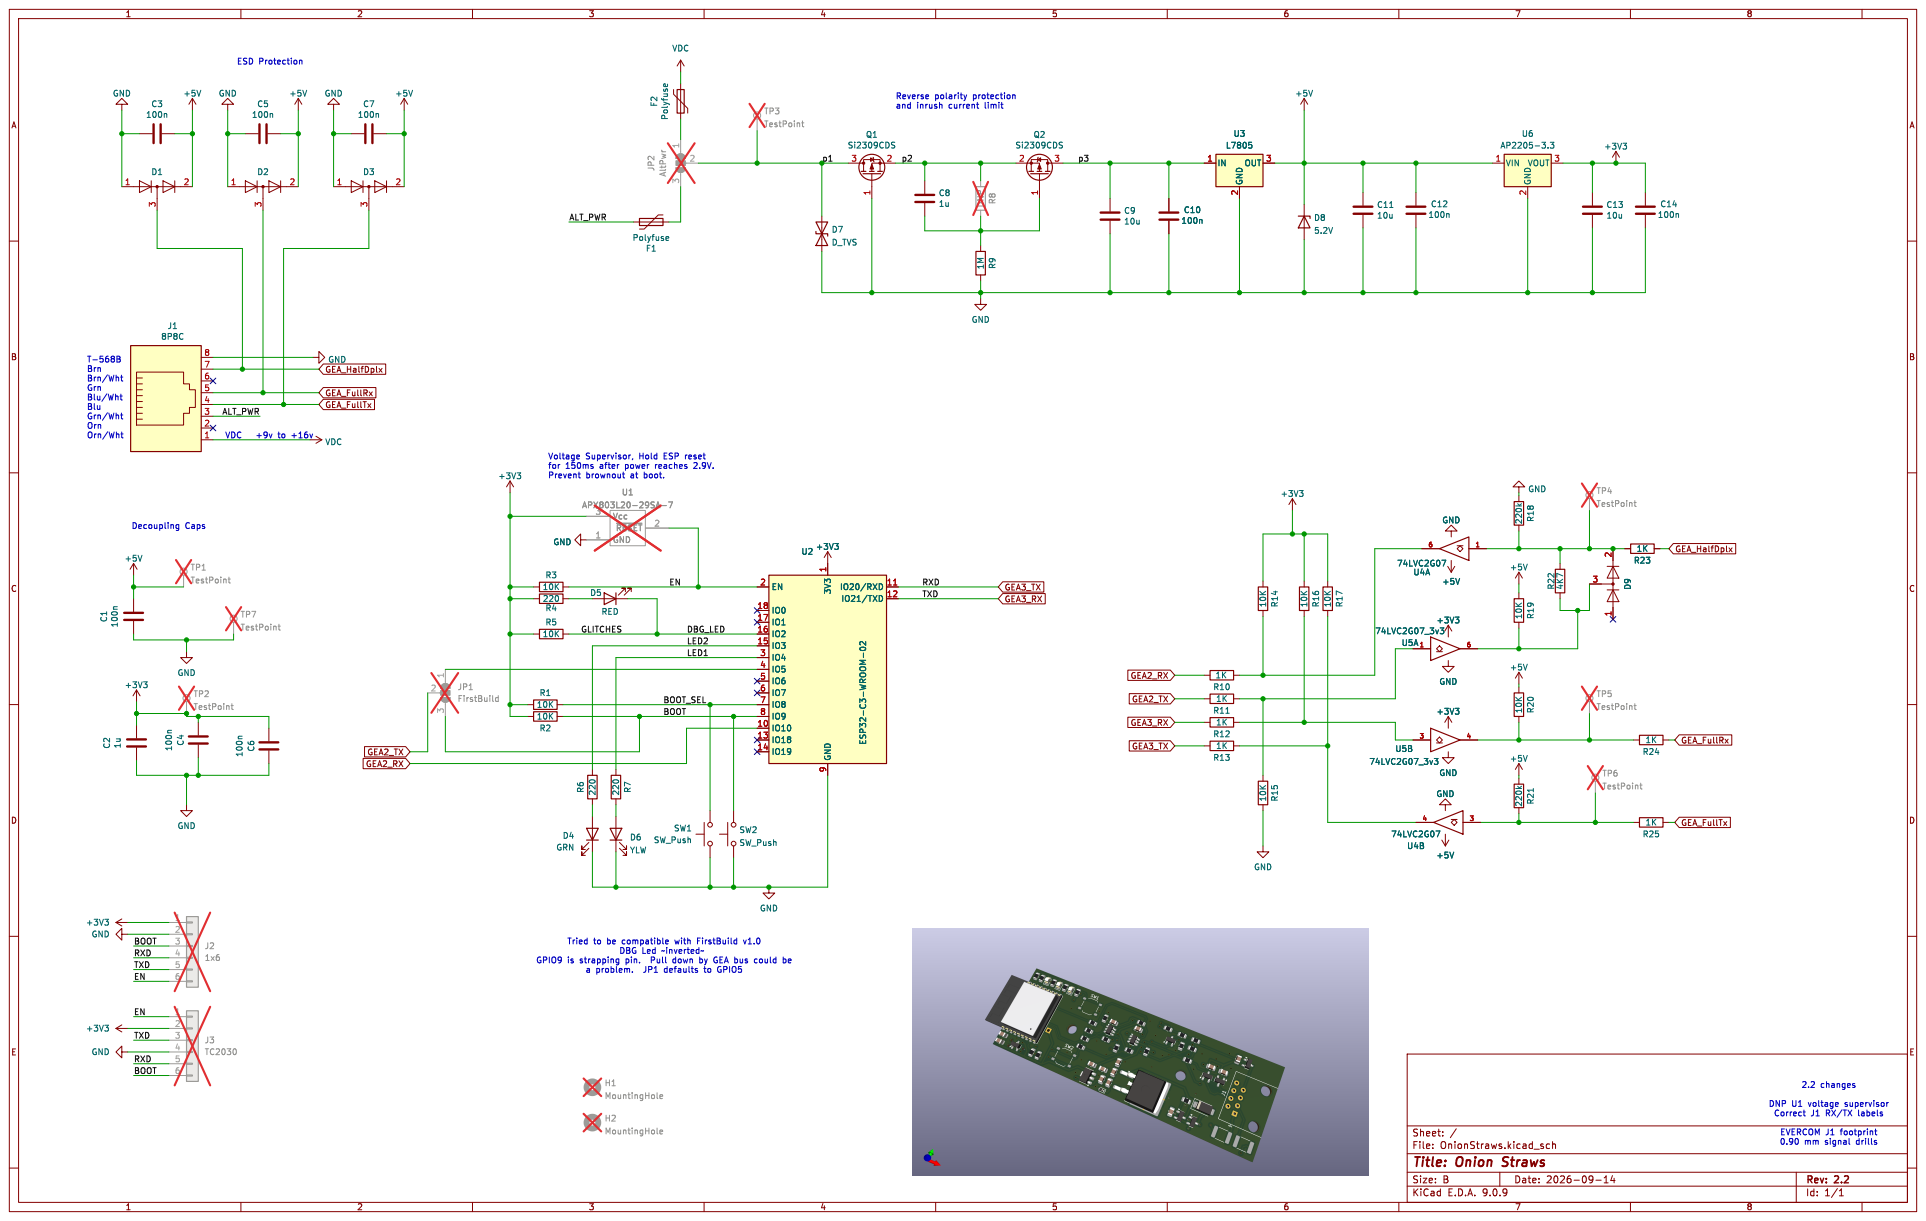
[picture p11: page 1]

File: OnionStraws.kicad_sch Sheet: / GND

2.2 changes DNP U1 voltage supervisor Correct J1 RX/TX labels EVERCOM J1 footprint 0.90 mm signal drills

Id: 1/1 Title: Onion Straws

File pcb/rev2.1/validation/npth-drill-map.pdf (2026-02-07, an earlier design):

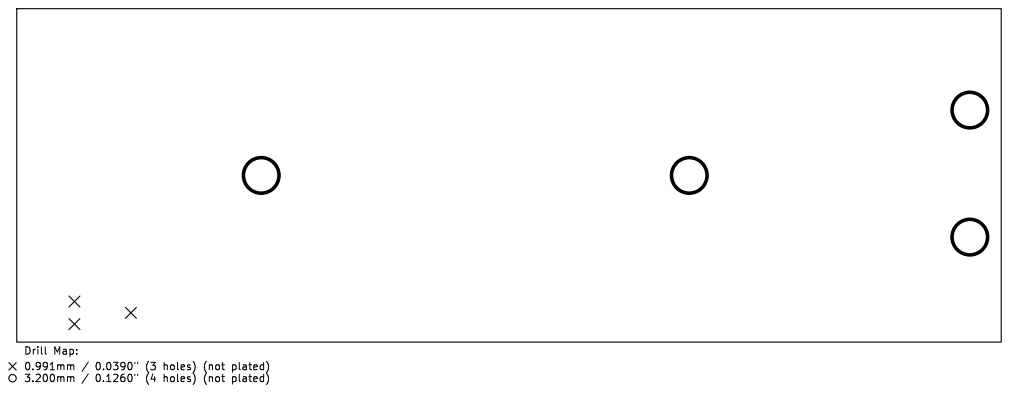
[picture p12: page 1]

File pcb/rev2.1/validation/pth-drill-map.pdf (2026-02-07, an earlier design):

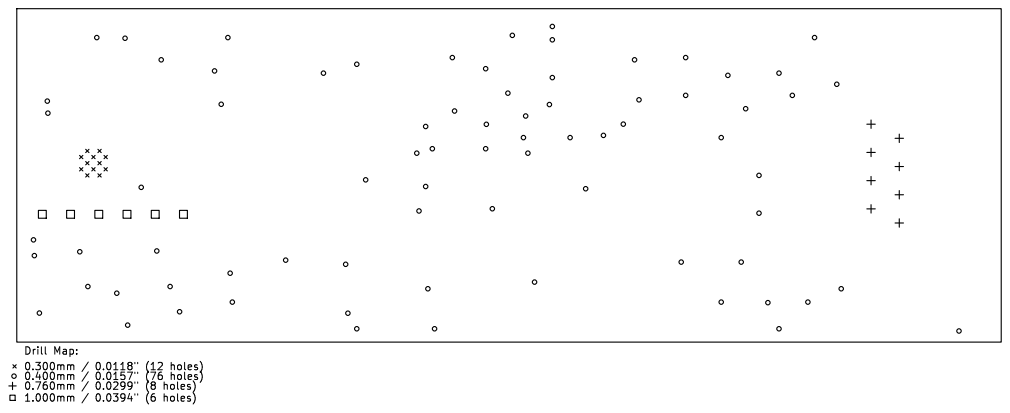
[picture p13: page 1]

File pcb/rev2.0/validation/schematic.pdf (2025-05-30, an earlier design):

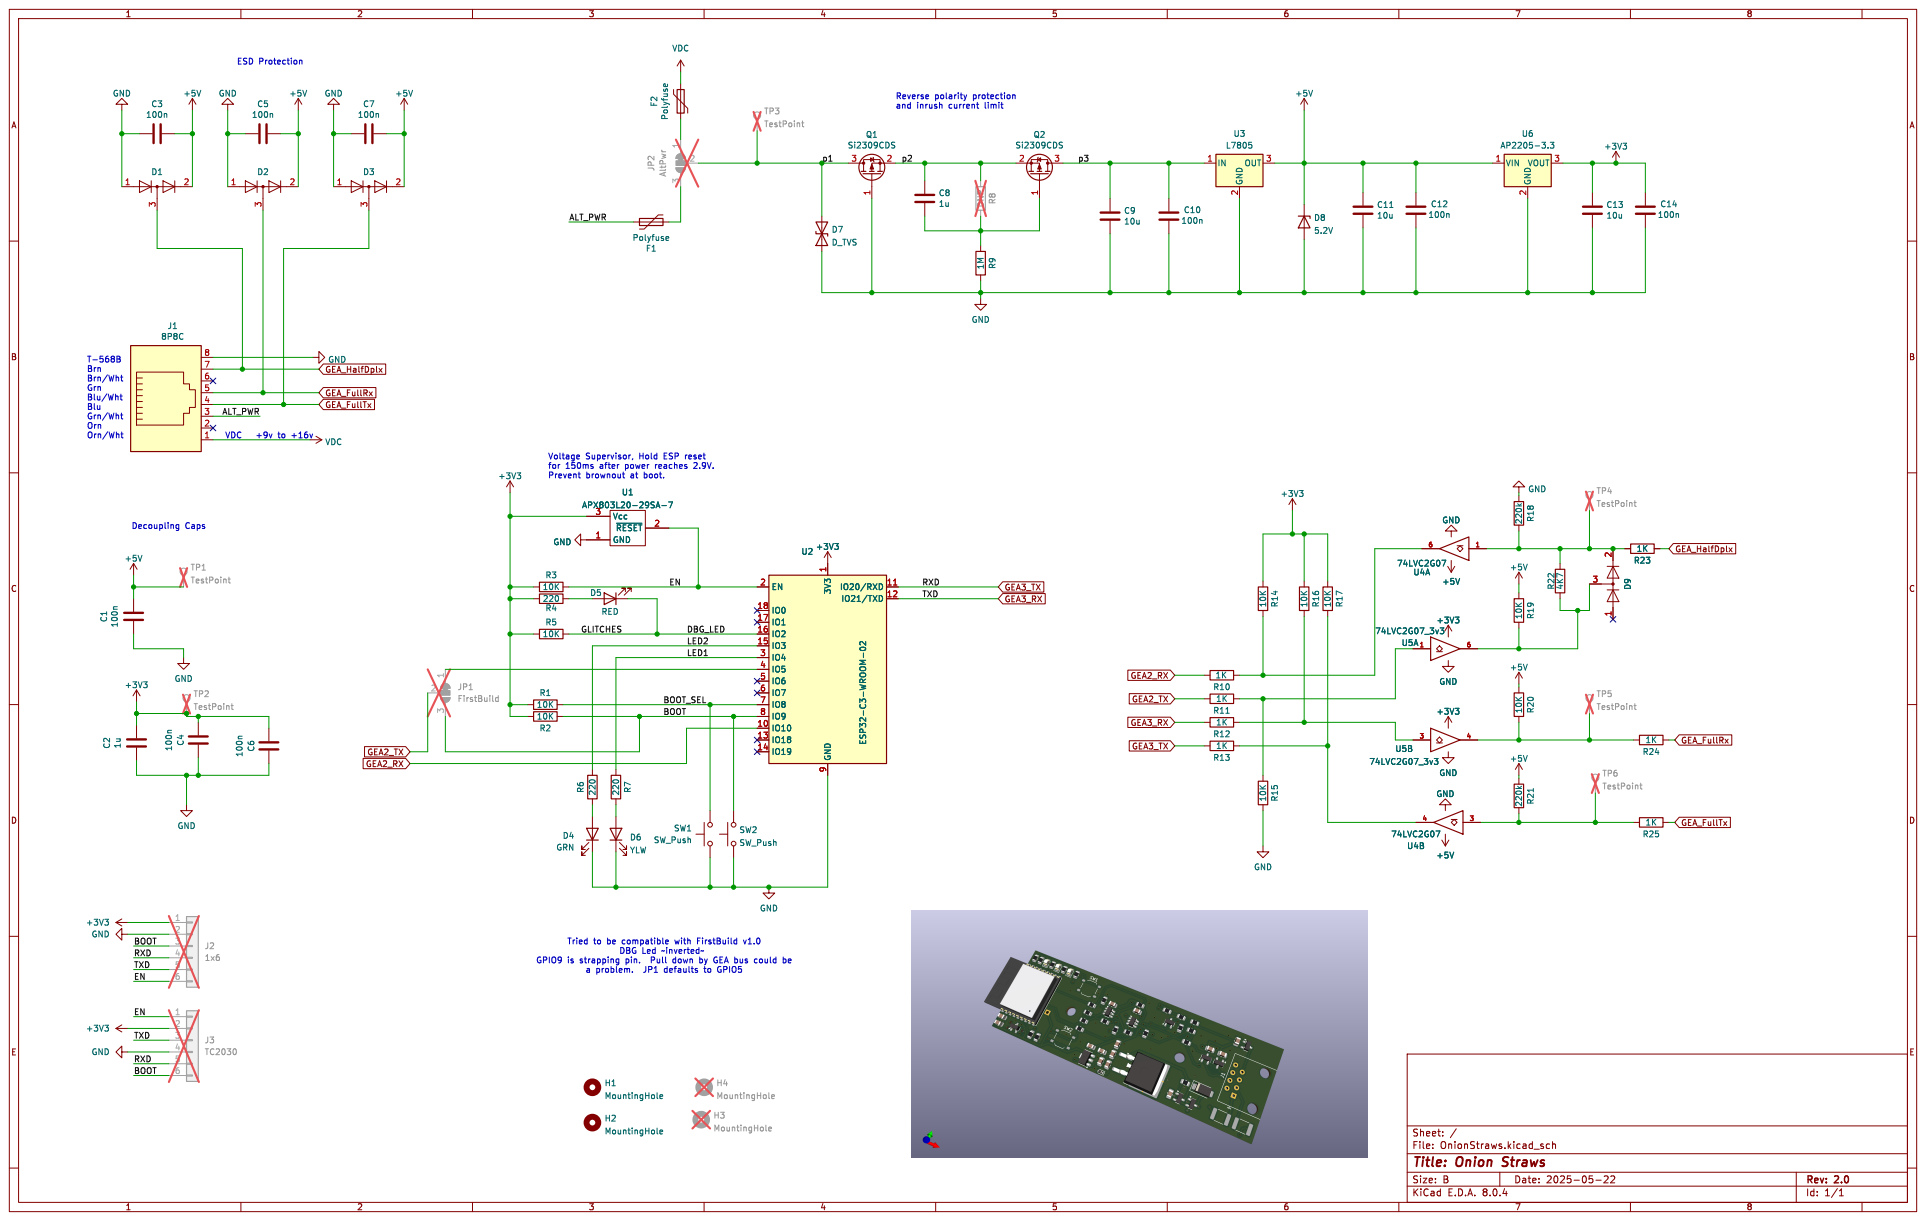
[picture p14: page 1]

Peak of 1.5 amps w/o inrush Dryer

Id: 1/1 Title: Onion Straws

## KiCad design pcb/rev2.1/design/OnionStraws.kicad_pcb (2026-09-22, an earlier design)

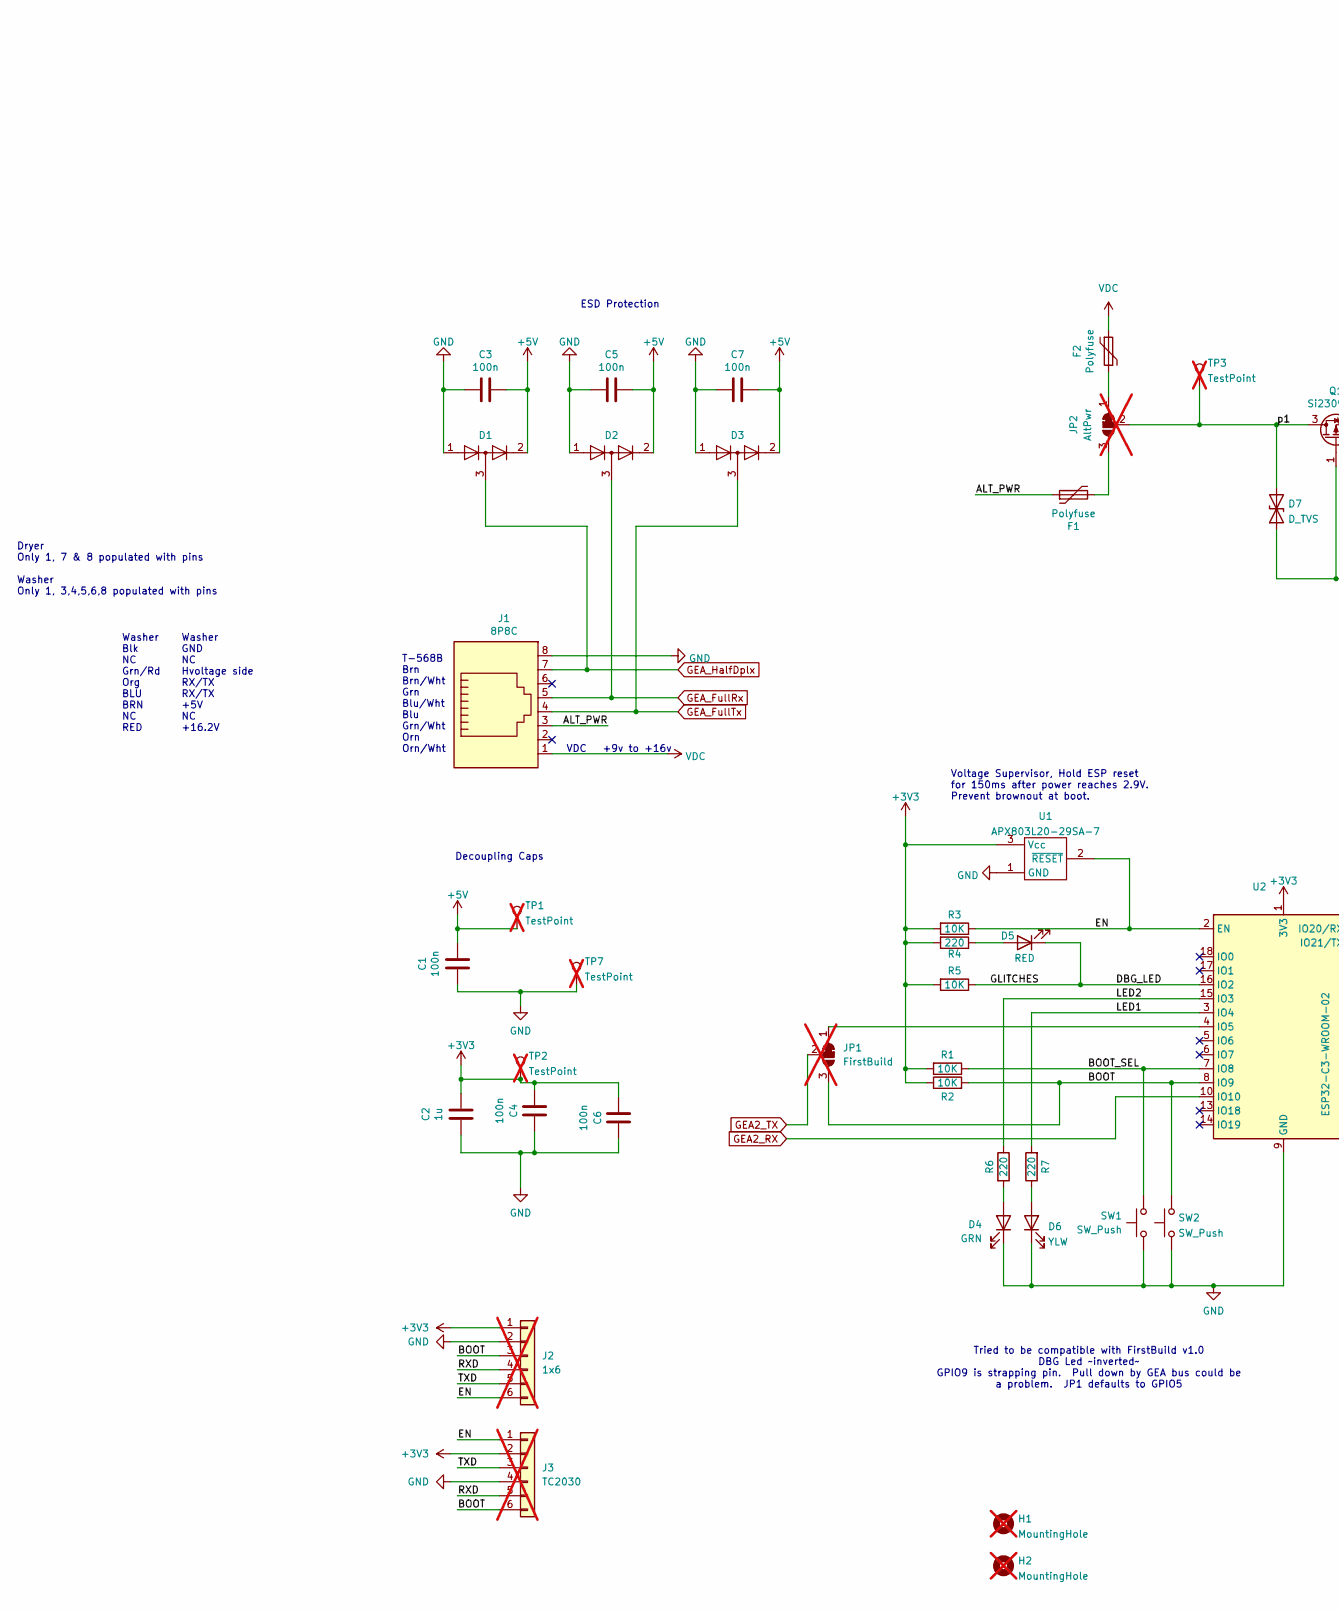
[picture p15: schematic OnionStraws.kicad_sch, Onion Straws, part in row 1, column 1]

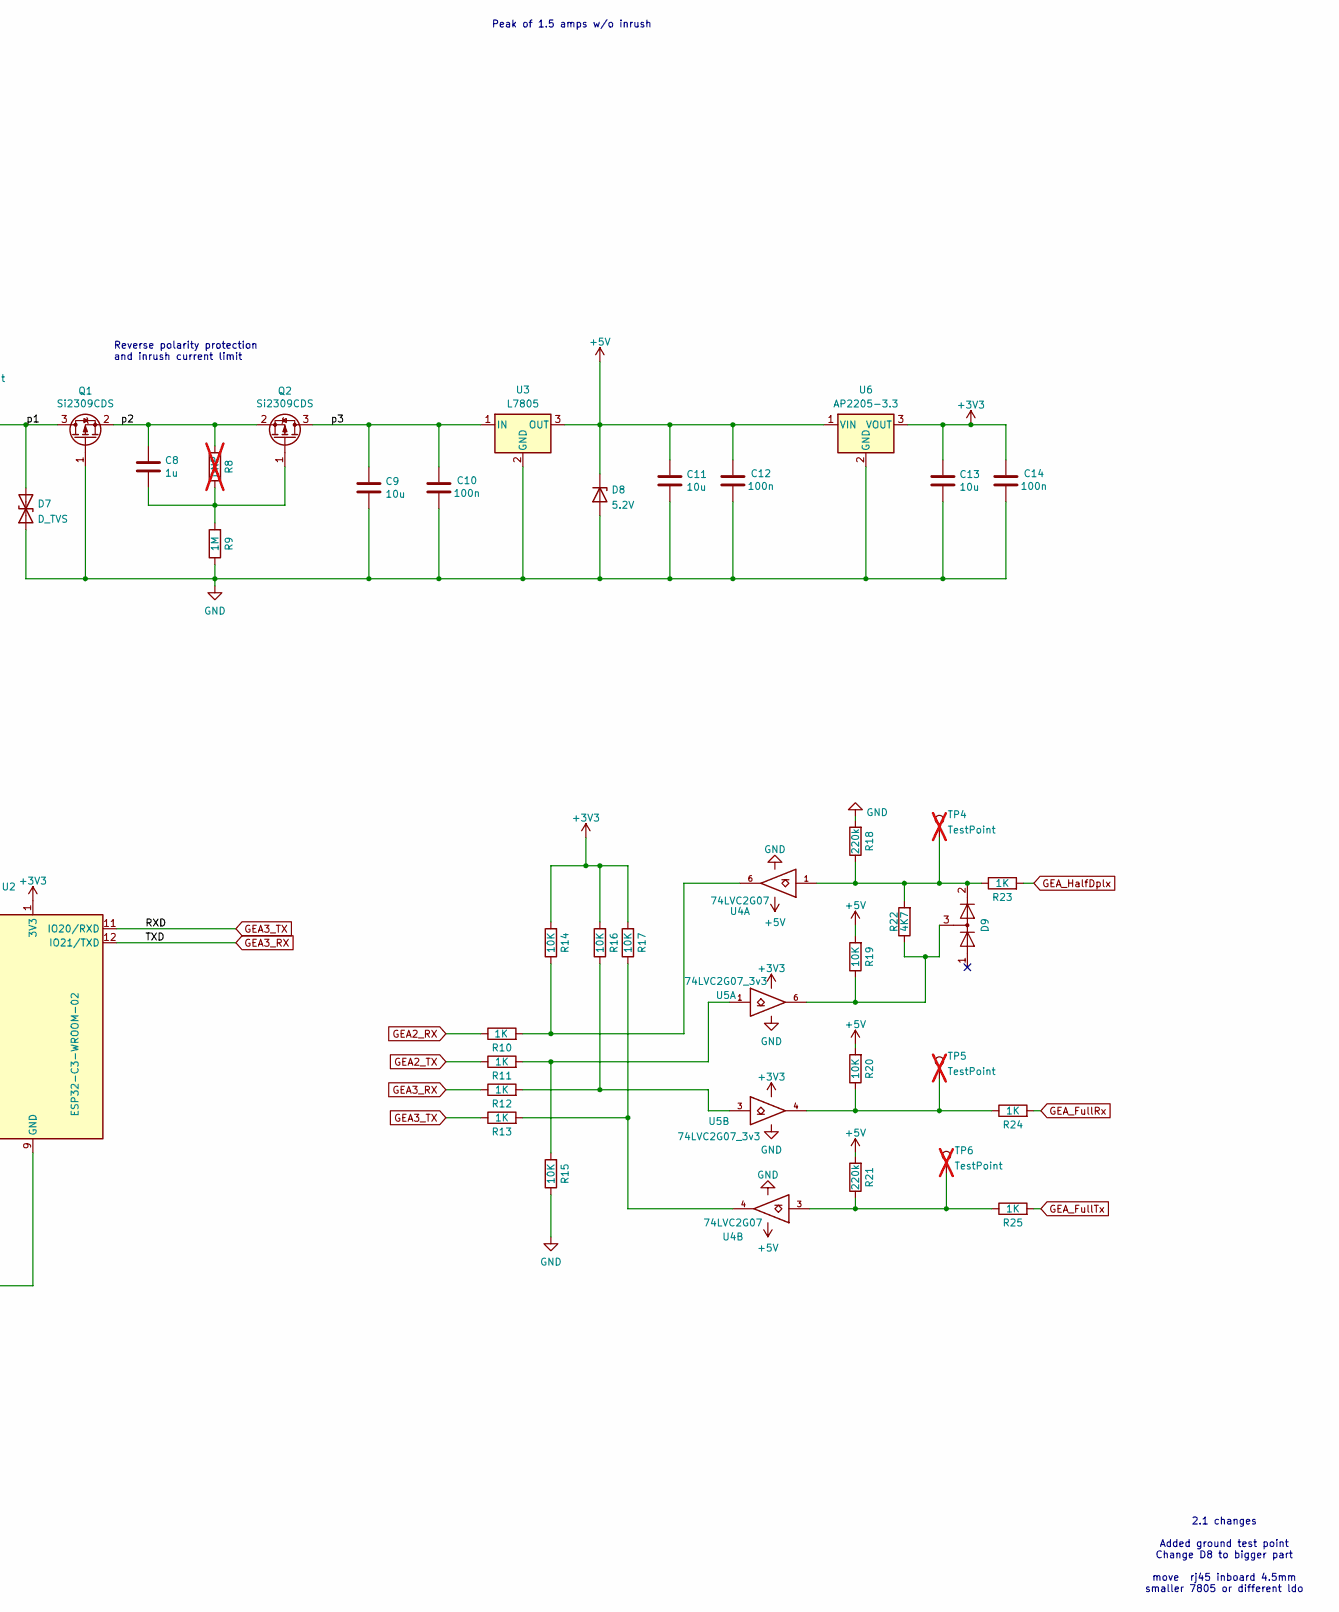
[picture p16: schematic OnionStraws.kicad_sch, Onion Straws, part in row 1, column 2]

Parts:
C1, C3, C4, C5, C6, C7, C10, C12, C14: 100n; C_0805_2012Metric; LCSC C28233
C2, C8: 1u; C_0805_2012Metric; LCSC C28323
C9, C11, C13: 10u; C_0805_2012Metric; LCSC C15850
D1, D2, D3, D9: BAV99; SOT-23; LCSC C2500
D4: GRN; LED_0805_2012Metric; LCSC C2297
D5: RED; LED_0805_2012Metric; LCSC C84256
D6: YLW; LED_0805_2012Metric; LCSC C2296
D7: D_TVS; D_SMA; LCSC C309871
D8: 5.2V; D_SOD-123; LCSC C78479
F1, F2: Polyfuse; Fuse_1812_4532Metric; LCSC C12604
H1, H2: MountingHole; MountingHole_3.2mm_M3_DIN965; not fitted
J1: 8P8C; RJ45_Amphenol_54602-x08_Horizontal; LCSC C3097717
J2: 1x6; PinHeader_1x06_P2.54mm_Vertical; not fitted
J3: TC2030; Tag-Connect_TC2030-IDC-NL_2x03_P1.27mm_Vertical; not fitted
JP1: FirstBuild; SolderJumper-3_P1.3mm_Bridged12_RoundedPad1.0x1.5mm_NumberL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; not fitted
JP2: AltPwr; SolderJumper-3_P1.3mm_Bridged12_RoundedPad1.0x1.5mm_NumberL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; not fitted
Q1: Si2309CDS; SOT-23
Q2: Si2309CDS; SOT-23; LCSC C10493
R1, R2, R3, R5, R14, R15, R16, R17, R19, R20: 10K; R_0805_2012Metric; LCSC C17414
R4, R6, R7: 220; R_0805_2012Metric; LCSC C17557
R8: DNP; R_0805_2012Metric; not fitted
R9: 1M; R_0805_2012Metric; LCSC C17514
R10, R11, R12, R13, R23, R24, R25: 1K; R_0805_2012Metric; LCSC C17513
R18, R21: 220k; R_0805_2012Metric; LCSC C17539
R22: 4K7; R_0805_2012Metric; LCSC C17713
SW1, SW2: SW_Push; SW_Push_1P1T_XKB_TS-1187A; LCSC C318884
TP1, TP2, TP3, TP4, TP5, TP6, TP7: TestPoint; TestPoint_Pad_D2.0mm; not fitted
U1: APX803L20-29SA-7; SOT-23; LCSC C2067355
U2: ESP32-C3-WROOM-02; LCSC C2934560
U3: L7805; TO-263-2; LCSC C86206
U4: 74LVC2G07; SOT-23-6; LCSC C151607
U5: 74LVC2G07_3v3; SOT-23-6; LCSC C151607
U6: AP2205-3.3; SOT-89-3; LCSC C5205181

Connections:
+3V3: C2.1, C4.2, C6.2, C13.1, C14.2, J2.1, J3.2, R1.2, R2.1, R3.2, R4.2, R5.2, R14.2, R16.2, R17.2, TP2.1, U1.3 (Vcc), U2.1 (3V3), U5.5 (+3V3), U6.3 (VOUT)
+5V: C1.1, C3.1, C5.1, C7.1, C11.1, C12.2, D1.2 (A), D2.2 (A), D3.2 (A), D8.1 (K), R19.2, R20.2, R21.2, TP1.1, U3.3 (OUT), U4.5 (VCC), U6.1 (VIN)
/ALT_PWR: F1.1, J1.3
/BOOT: J2.3, J3.6, JP1.3 (B), R2.2, SW2.2, U2.8 (IO9)
/BOOT_SEL: R1.1, SW1.1, U2.7 (IO8)
/DBG_LED: D5.1 (K), R5.1, U2.16 (IO2)
/EN: J2.6, J3.1, R3.1, U1.2 (~RESET), U2.2 (EN)
/LED1: R7.2, U2.3 (IO4)
/LED2: R6.1, U2.15 (IO3)
/p1: D7.2 (A2), JP2.2 (C), Q1.3 (D), TP3.1
/p2: C8.1, Q1.2 (S), Q2.2 (S), R8.2
/p3: C9.1, C10.2, Q2.3 (D), U3.1 (IN)
GEA2_RX: R10.1, U2.10 (IO10)
GEA2_TX: JP1.2 (C), R11.1
GEA3_RX: J2.5, J3.3, R12.1, U2.12 (IO21/TXD)
GEA3_TX: J2.4, J3.5, R13.1, U2.11 (IO20/RXD)
GEA_FullRx: D2.3 (K), J1.5, R24.2
GEA_FullTx: D3.3 (K), J1.4, R25.2
GEA_HalfDplx: D1.3 (K), J1.7, R23.2
GND: C1.2, C2.2, C3.2, C4.1, C5.2, C6.1, C7.2, C9.2, C10.1, C11.2, C12.1, C13.2, C14.1, D1.1 (K), D2.1 (K), D3.1 (K), D4.1 (K), D6.1 (K), D7.1 (A1), D8.2 (A), J1.8, J2.2, J3.4, Q1.1 (G), R9.1, R15.1, R18.2, SW1.2, SW2.1, TP7.1, U1.1 (GND), U2.9 (GND), U2.19 (GND), U3.2 (GND), U4.2 (GND), U5.2 (GND), U6.2 (GND)
unnamed: D4.2 (A), R6.2
unnamed: D5.2 (A), R4.1
unnamed: D6.2 (A), R7.1
unnamed: D9.2 (A), R18.1, R22.2, R23.1, TP4.1, U4.1
unnamed: D9.3 (K), R19.1, R22.1, U5.6
unnamed: JP1.1 (A), U2.4 (IO5)
unnamed: F2.2, JP2.1 (A)
unnamed: F1.2, JP2.3 (B)
unnamed: C8.2, Q2.1 (G), R8.1, R9.2
unnamed: R10.2, R14.1, U4.6
unnamed: R11.2, R15.2, U5.1
unnamed: R12.2, R16.1, U5.3
unnamed: R13.2, R17.1, U4.4
unnamed: R20.1, R24.1, TP5.1, U5.4
unnamed: R21.1, R25.1, TP6.1, U4.3
VDC: F2.1, J1.1

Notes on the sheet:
Voltage Supervisor, Hold ESP reset for 150ms after power reaches 2.9V. Prevent brownout at boot.
Washer Blk NC Grn/Rd Org BLU BRN NC RED
Reverse polarity protection and inrush current limit
Dryer Only 1, 7 & 8 populated with pins Washer Only 1, 3,4,5,6,8 populated with pins
Tried to be compatible with FirstBuild v1.0 DBG Led ~inverted~ GPIO9 is strapping pin. Pull down by GEA bus could be a problem. JP1 defaults to GPIO5
2.1 changes Added ground test point Change D8 to bigger part move rj45 inboard 4.5mm smaller 7805 or different ldo
Washer GND NC Hvoltage side RX/TX RX/TX +5V NC +16.2V
Decoupling Caps
Peak of 1.5 amps w/o inrush
ESD Protection
T-568B Brn Brn/Wht Grn Blu/Wht Blu Grn/Wht Orn Orn/Wht
VDC +9v to +16v

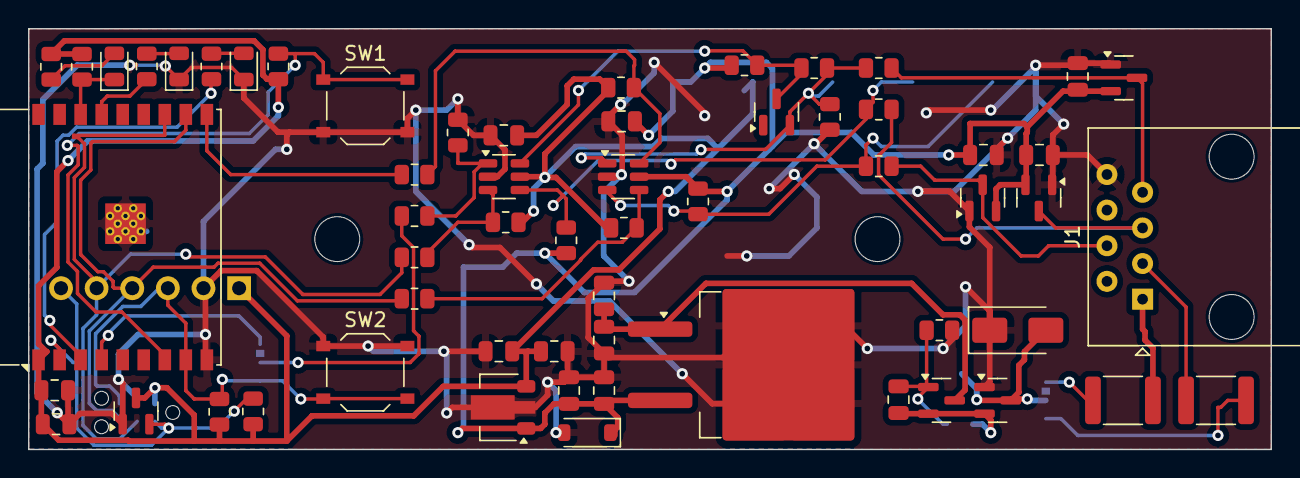
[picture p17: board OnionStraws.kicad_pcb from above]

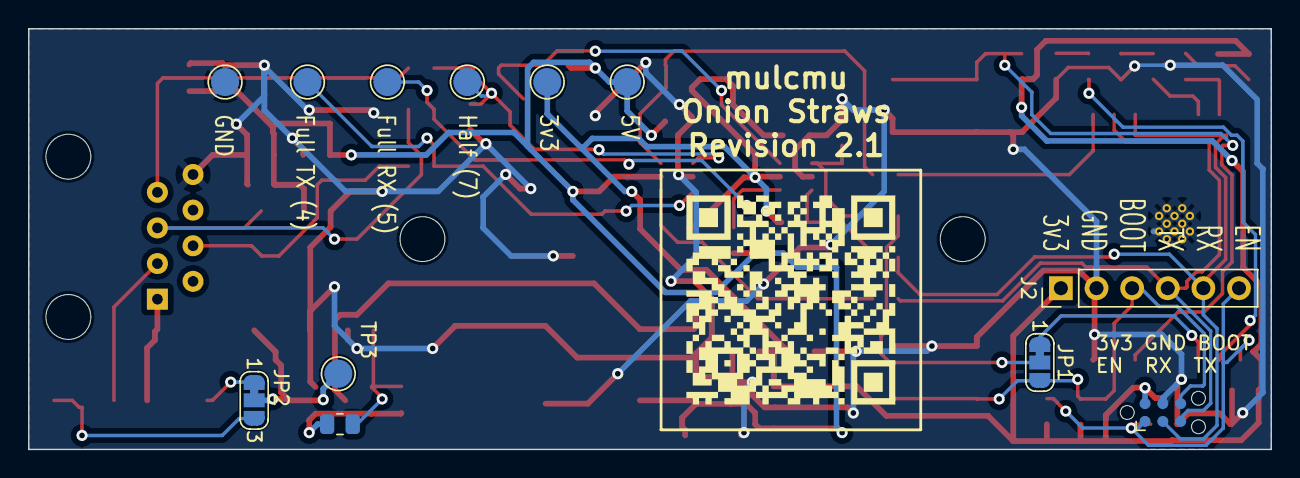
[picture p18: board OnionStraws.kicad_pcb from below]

Board: 2 copper layers, 88.6 x 30.0 mm, 74 parts (12 on the bottom side), 36 nets.

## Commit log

2021-12-21 Add wifi status led
2022-01-01 add draft pcb files
    [OnionStraws.kicad_sch]
2022-01-04 Updated PCB
    [OnionStraws.kicad_sch]
2022-01-15 dual uart for logging
    2nd uart added for logging both sides of the U+ to Washer communication.
2022-01-15 Update PCB for full duplex
    ESP tx to washer not tested yet
    [OnionStraws.kicad_sch]
2022-01-17 add text for washer sensors
2022-01-19 Rev 0.1 of PCB
    [OnionStraws.kicad_pcb, OnionStraws.kicad_sch]
2022-01-20 Rev 0.2 PCB
    Fix unconnected GND pads
    [OnionStraws.kicad_pcb]
2022-01-29 PCB Rev 0.3
    Fixed D4 and related pull up resistors.
    Added LED and PB
    Added 5V zener diode and TVS for input
    [OnionStraws.kicad_pcb, OnionStraws.kicad_sch]
2022-01-29 add pcb readme
2022-01-29 Dryer setup for pcb
2022-02-21 Add BOM
    Add BOM
2022-02-24 Dryer yaml has button/led config
2022-03-25 PCB Rev 1.0
    [OnionStraws.kicad_pcb, OnionStraws.kicad_sch]
2022-06-22 Add Case
    [Case v7.f3d, onion straw case lid.stl, onion straw case.stl]
2022-06-23 Add lid with holes
    v7 is plain lid, v8 has holes
    [Case v8.f3d, onion straw case lid holes.stl]
2025-05-11 validation framework for external component
2025-05-30 v2 beta
    [OnionStraws-B_Cu.gbr, OnionStraws-B_Mask.gbr, OnionStraws-B_Silkscreen.gbr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]
2025-05-30 update v2 case
    [Case v7.f3d, Case v8.f3d, onion straw case lid holes.stl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]
2025-06-12 pcb 2.1 mods
    [OnionStraws.kicad_pcb, OnionStraws.kicad_sch]
2025-06-12 add case stls
    [os case v2 base.stl, os case v2 lid.stl]
2025-06-12 case cleanup
2026-02-07 Migrate PCB to KiCad 9; add JLC gerbers
    [BOM-OnionStraws.csv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]
2026-05-21 Update repo for current status
    Remove the old local gea_adapter implementation and legacy example YAMLs/docs (washer.yaml, dryer.yaml, dishwasher.yaml, erds.md) along with associated C++/Python component files. Add new GEA2 and GEA3 ESPhome templates (gea2.yaml, gea3.yaml) that use the external mguaylam/esphome-gea component, include diagnostic sensors, LED outputs, and bus/uart configuration. Update README to document the migration, PCB issues and next steps, and add a PCB image (pcb/v2 fix.png); small update to pcb/readme.md preserved.
2026-09-22 Reorg and add Rev 2.2 PCB
    * chore(repo): organize hardware revisions and firmware
    * fix(pcb): prepare revision 2.2 design source
    * build(pcb): add revision 2.2 manufacturing package
    * docs(pcb): document revision 2.2 ordering and validation
    [BOM-OnionStraws-rev2.1.csv, BOM-OnionStraws-rev2.2.csv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]
